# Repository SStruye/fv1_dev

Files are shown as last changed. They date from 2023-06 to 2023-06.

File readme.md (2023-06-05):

# FV1 dev board
the FV1 is a widely used reverb/effect I2C that is programmable.
I build a dev board around it for use as a guitar pedal design platform. <br>

the devboard provides:
-  an onboard usb programmer
-  buffered in and output
-  3 positional dip switch for the FV1,
-  3 variable resistor for the FV1 
-  1 variable resistor for volume 
-  1 variable resistor for mixing the clean and effects signal.

The 3 dip switch can be used to select presets or for use with custom software. The 3 variable resistors are there to adjust paramaters such as time, rise, rate, depth etc. <br>
a 4 layer pcb design was made for better signal integrity.
Some small mistakes are still in the design but it works. (e.g. wrong 3.3V regulator footprint)
Further improvements won't be added for the foreseeable future as intrests shifted.

## PCB design
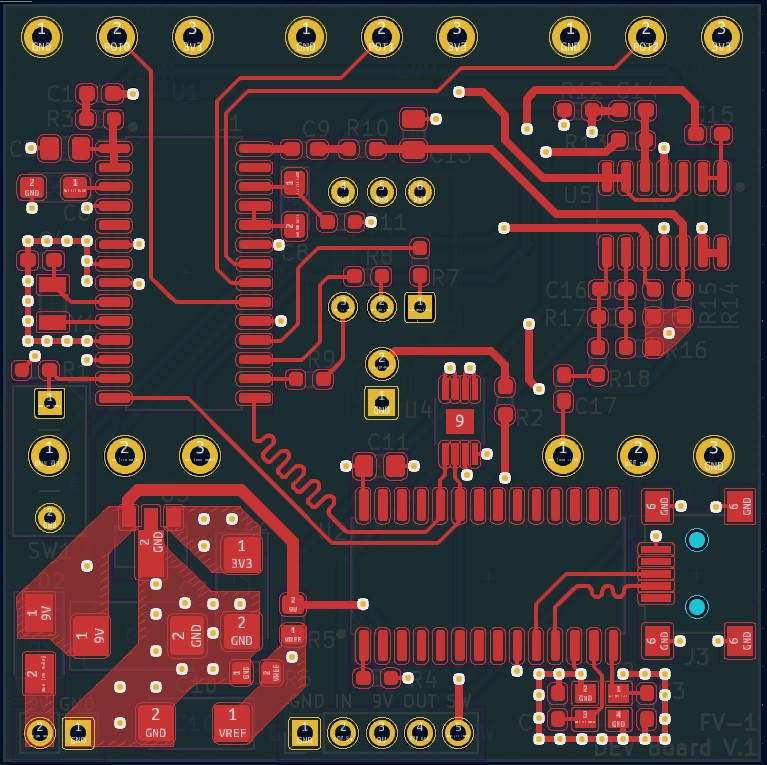
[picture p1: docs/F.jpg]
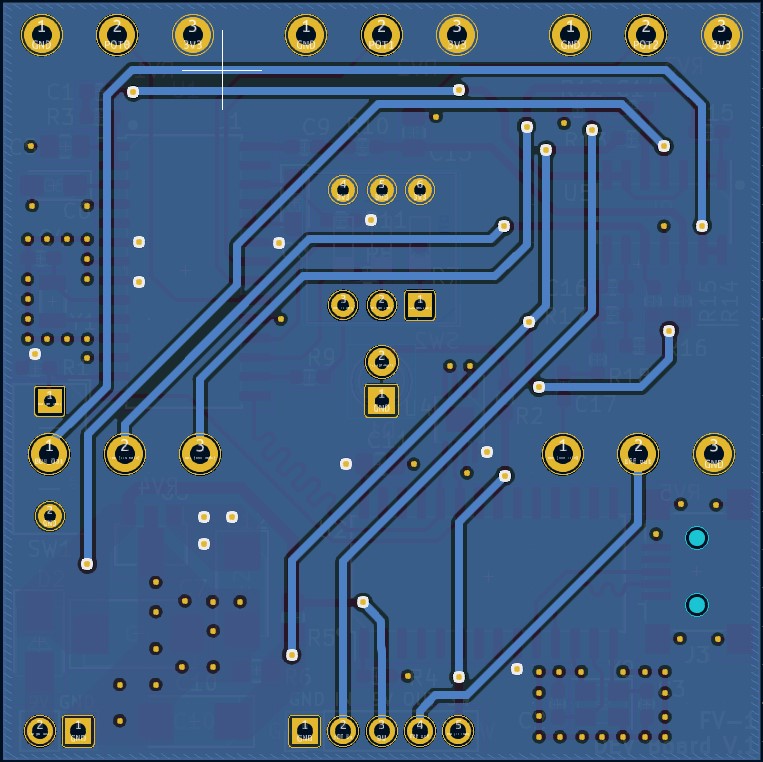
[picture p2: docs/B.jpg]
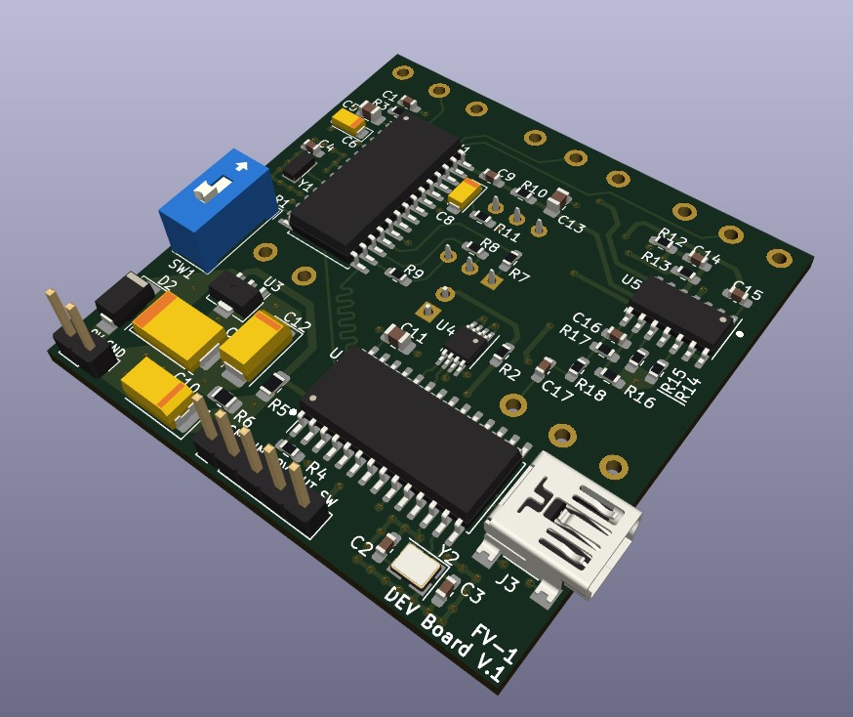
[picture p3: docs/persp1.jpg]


## result
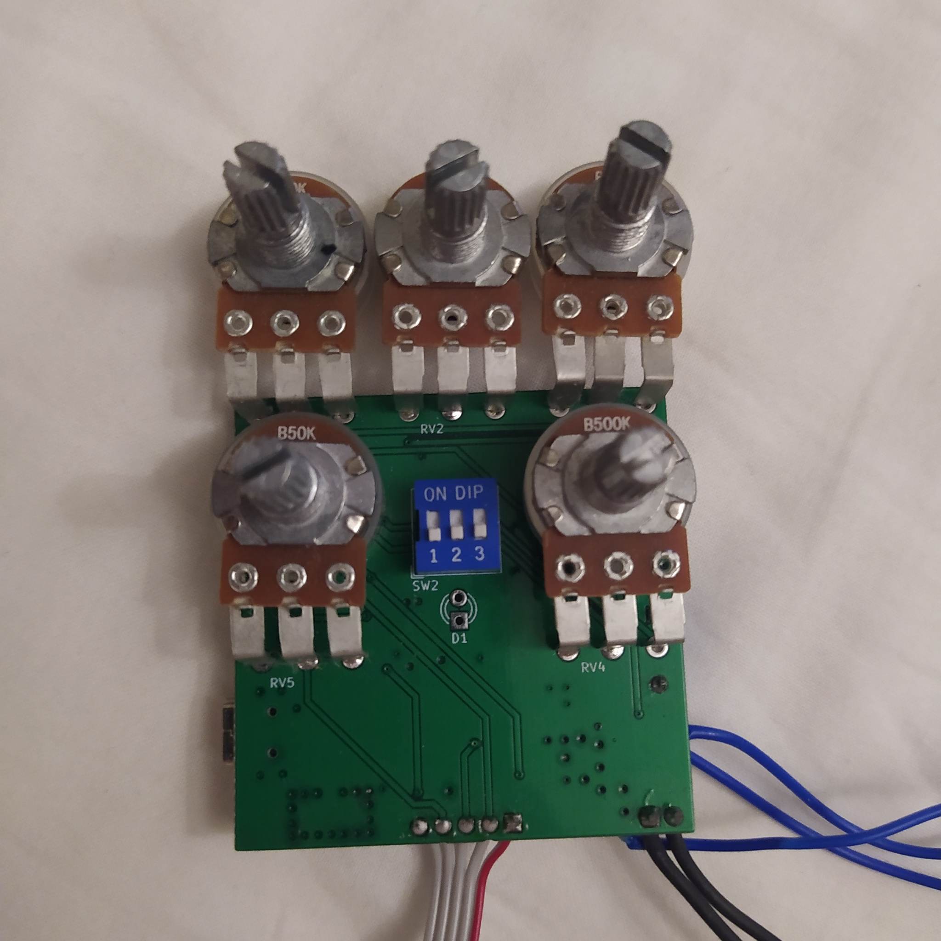
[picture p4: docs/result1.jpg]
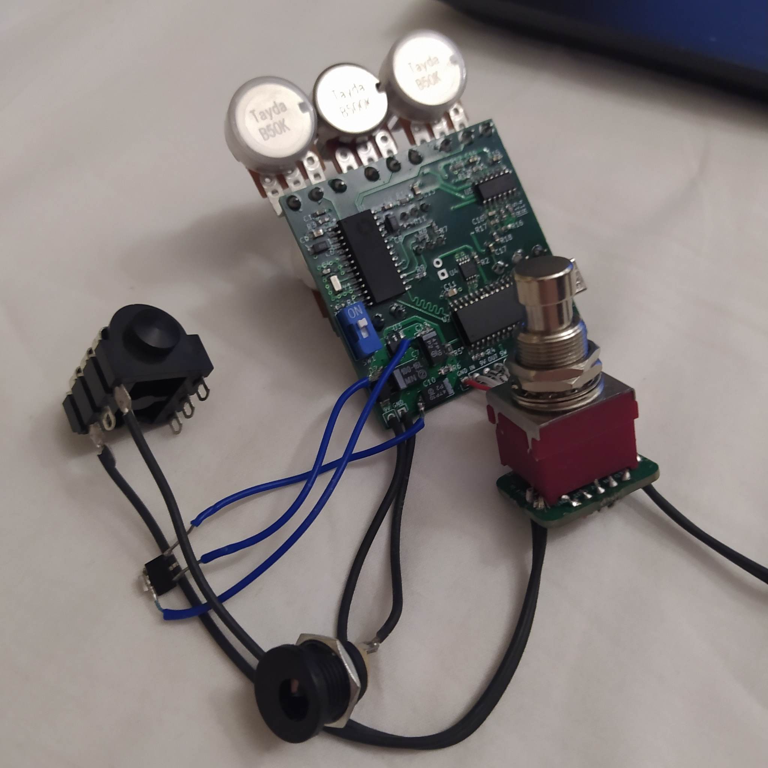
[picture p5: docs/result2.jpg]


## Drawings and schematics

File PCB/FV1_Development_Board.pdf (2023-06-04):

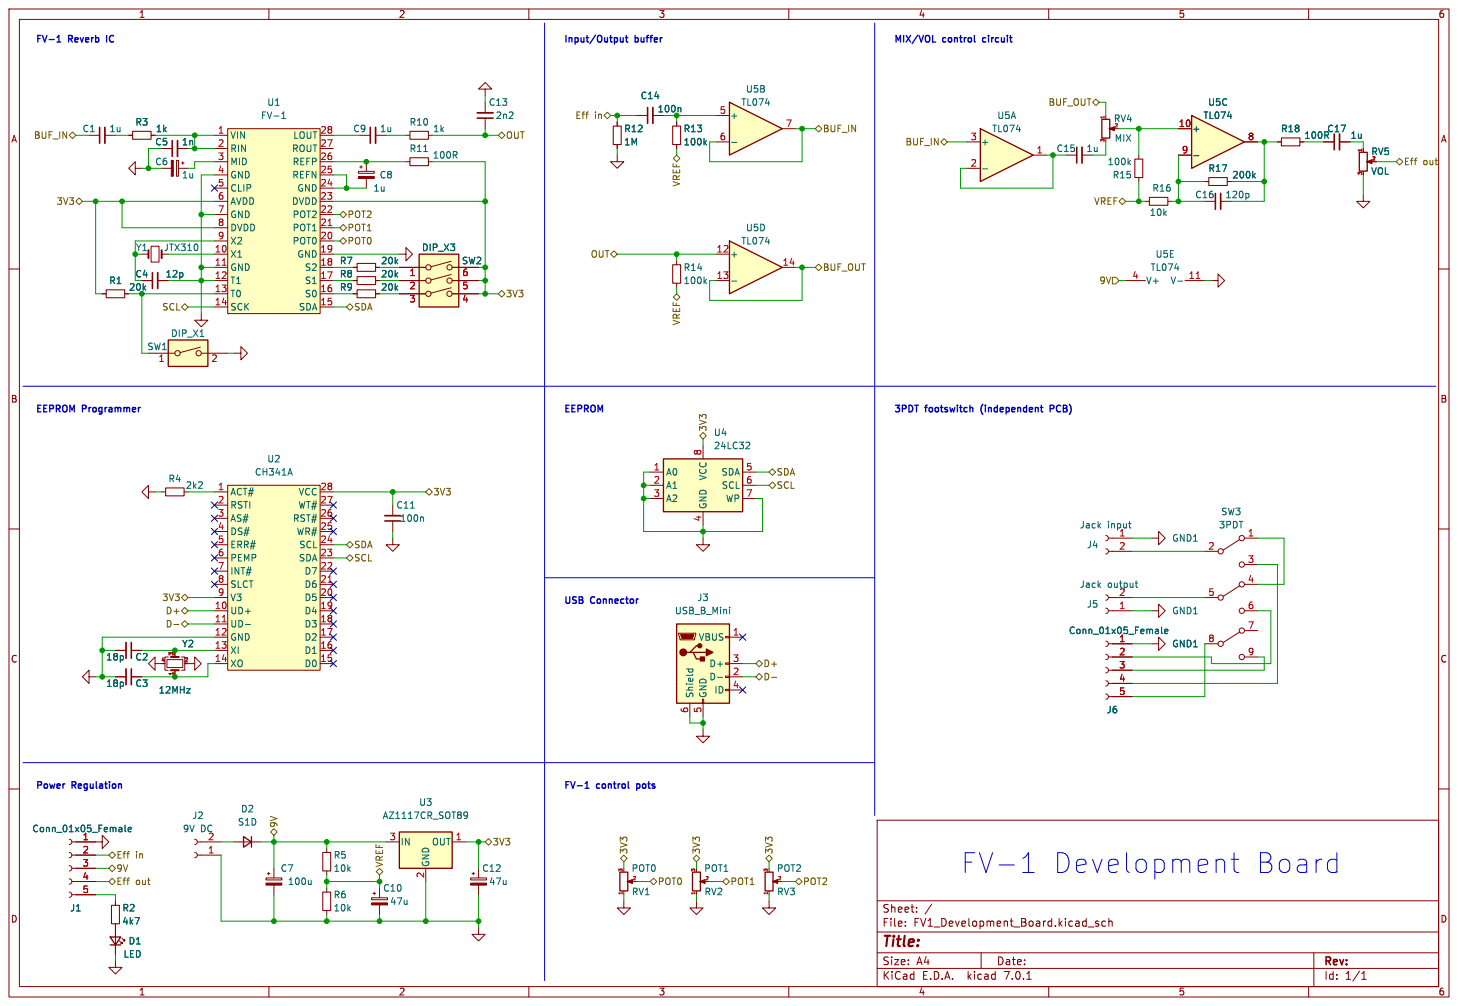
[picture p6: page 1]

4 SDA 5 SCL 6 WP 7 VCC

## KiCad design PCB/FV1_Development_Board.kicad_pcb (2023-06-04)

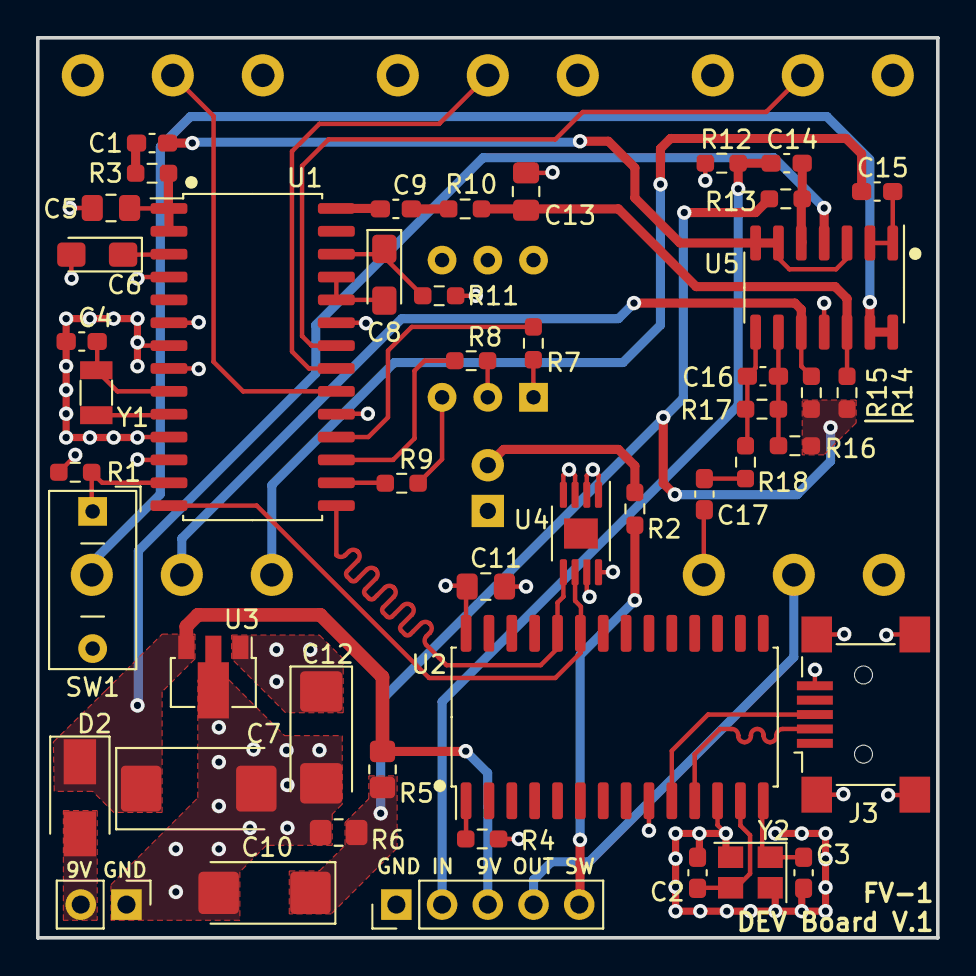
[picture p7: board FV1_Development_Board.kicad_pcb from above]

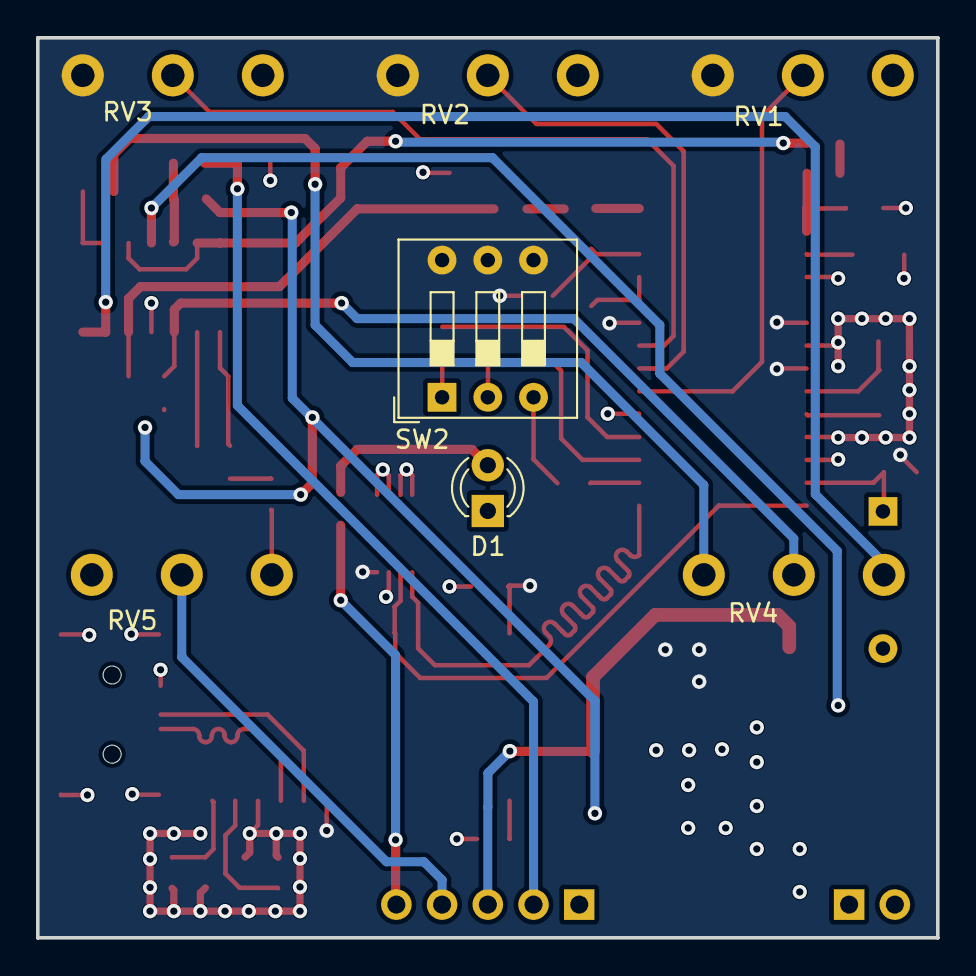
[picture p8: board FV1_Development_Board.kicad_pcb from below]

Board: 4 copper layers, 50.0 x 50.0 mm, 54 parts (7 on the bottom side), 46 nets.

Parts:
9V GND: 9V DC; PinHeader_1x02_P2.54mm_Vertical
C1, C9, C15, C17: 1u; C_0603_1608Metric_Pad1.08x0.95mm_HandSolder
C2, C3: 18p; C_0603_1608Metric_Pad1.08x0.95mm_HandSolder
C4: 12p; C_0603_1608Metric_Pad1.08x0.95mm_HandSolder
C5: 1n; C_0805_2012Metric_Pad1.18x1.45mm_HandSolder
C6, C8: 1u; CP_EIA-3216-10_Kemet-I_Pad1.58x1.35mm_HandSolder
C7: 100u; CP_EIA-7343-20_Kemet-V_Pad2.25x2.55mm_HandSolder
C10, C12: 47u; CP_EIA-6032-28_Kemet-C_Pad2.25x2.35mm_HandSolder
C11: 100n; C_0805_2012Metric_Pad1.18x1.45mm_HandSolder
C13: 2n2; C_0805_2012Metric_Pad1.18x1.45mm_HandSolder
C14: 100n; C_0603_1608Metric_Pad1.08x0.95mm_HandSolder
C16: 120p; C_0603_1608Metric_Pad1.08x0.95mm_HandSolder
D1: LED; LED_D3.0mm
D2: S1D; D_SMA
GND IN  9V OUT SW: Conn_01x05_Female; PinHeader_1x05_P2.54mm_Vertical
J3: USB_B_Mini; USB_Mini-B_Lumberg_2486_01_Horizontal
R1, R7, R8, R9: 20k; R_0603_1608Metric_Pad0.98x0.95mm_HandSolder
R2: 4k7; R_0603_1608Metric_Pad0.98x0.95mm_HandSolder
R3, R10: 1k; R_0603_1608Metric_Pad0.98x0.95mm_HandSolder
R4: 2k2; R_0603_1608Metric_Pad0.98x0.95mm_HandSolder
R5, R6: 10k; R_0805_2012Metric_Pad1.20x1.40mm_HandSolder
R11, R18: 100R; R_0603_1608Metric_Pad0.98x0.95mm_HandSolder
R12: 1M; R_0603_1608Metric_Pad0.98x0.95mm_HandSolder
R13, R14, R15: 100k; R_0603_1608Metric_Pad0.98x0.95mm_HandSolder
R16: 10k; R_0603_1608Metric_Pad0.98x0.95mm_HandSolder
R17: 200k; R_0603_1608Metric_Pad0.98x0.95mm_HandSolder
RV1: POT0; Potentiometer_Omeg_PC16BU_Vertical
RV2: POT1; Potentiometer_Omeg_PC16BU_Vertical
RV3: POT2; Potentiometer_Omeg_PC16BU_Vertical
RV4: MIX; Potentiometer_Omeg_PC16BU_Vertical
RV5: VOL; Potentiometer_Omeg_PC16BU_Vertical
SW1: DIP_X1; SW_DIP_SPSTx01_Slide_9.78x4.72mm_W7.62mm_P2.54mm
SW2: DIP_X3; SW_DIP_SPSTx03_Slide_9.78x9.8mm_W7.62mm_P2.54mm
U1: FV-1; FV1
U2: CH341A
U3: AZ1117CR_SOT89; SOT-89-3
U4: 24LC32; MSOP-8-1EP_3x3mm_P0.65mm_EP1.68x1.88mm
U5: TL074; SOIC-14_3.9x8.7mm_P1.27mm
Y1: JTX310; Crystal_SMD_3215-2Pin_3.2x1.5mm
Y2: 12MHz; Crystal_SMD_Abracon_ABM8G-4Pin_3.2x2.5mm

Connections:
/3V3: C11.2, C12.1, R1.1, R11.2, RV1.3, RV2.3, RV3.3, SW2.4, SW2.5, SW2.6, U1.6 (AVDD), U1.8 (DVDD), U1.23 (DVDD), U2.9 (V3), U2.28 (VCC), U3.1 (OUT), U4.8 (VCC)
/9V: C7.1, D2.1 (K), GND IN 9V OUT SW.3, R5.2, U3.3 (IN), U5.4 (V+)
/BUF_IN: C1.1, U5.3 (+), U5.6 (-), U5.7
/BUF_OUT: RV4.1, U5.13 (-), U5.14
/D+: J3.3 (D+), U2.10 (UD+)
/D-: J3.2 (D-), U2.11 (UD-)
/Eff in: C14.1, GND IN 9V OUT SW.2, R12.2
/Eff out: GND IN 9V OUT SW.4, RV5.2
/OUT: C13.1, R10.2, R14.2, U5.12 (+)
/POT0: RV1.2, U1.20 (POT0)
/POT1: RV2.2, U1.21 (POT1)
/POT2: RV3.2, U1.22 (POT2)
/SCL: U1.14 (SCK), U2.23 (SDA), U4.6 (SCL)
/SDA: U1.15 (SDA), U2.24 (SCL), U4.5 (SDA)
/VREF: C10.1, R5.1, R6.2, R13.1, R14.1, R15.2, R16.1
GND: 9V GND.1, C2.2, C3.2, C4.2, C5.1, C6.2, C7.2, C10.2, C11.1, C12.2, C13.2, D1.1 (K), GND IN 9V OUT SW.1, J3.5 (GND), J3.6 (Shield), R4.1, R6.1, R12.1, RV1.1, RV2.1, RV3.1, RV5.3, SW1.2, U1.4 (GND), U1.7 (GND), U1.11 (GND), U1.12 (T1), U1.19 (GND), U2.12 (GND), U3.2 (GND), U4.1 (A0), U4.2 (A1), U4.3 (A2), U4.4 (GND), U4.7 (WP), U5.11 (V-), Y2.2, Y2.4
unnamed: C1.2, R3.1
unnamed: C2.1, U2.13 (XI), Y2.3
unnamed: C3.1, U2.14 (XO), Y2.1
unnamed: C4.1, U1.9 (X2), Y1.1
unnamed: C5.2, R3.2, U1.1 (VIN), U1.2 (RIN)
unnamed: C6.1, U1.3 (MID)
unnamed: C8.1, R11.1, U1.26 (REFP)
unnamed: C8.2, U1.24 (GND), U1.25 (REFN)
unnamed: C9.1, U1.28 (LOUT)
unnamed: C9.2, R10.1
unnamed: C14.2, R13.2, U5.5 (+)
unnamed: C15.1, U5.1, U5.2 (-)
unnamed: C15.2, RV4.3
unnamed: C16.1, R16.2, R17.1, U5.9 (-)
unnamed: C16.2, R17.2, R18.1, U5.8
unnamed: C17.1, R18.2
unnamed: C17.2, RV5.1
unnamed: D1.2 (A), R2.1
unnamed: 9V GND.2, D2.2 (A)
unnamed: GND IN 9V OUT SW.5, R2.2
unnamed: R1.2, SW1.1, U1.13 (T0)
unnamed: R4.2, U2.1 (ACT#)
unnamed: R7.1, SW2.1
unnamed: R7.2, U1.18 (S2)
unnamed: R8.1, SW2.2
unnamed: R8.2, U1.17 (S1)
unnamed: R9.1, SW2.3
unnamed: R9.2, U1.16 (S0)
unnamed: R15.1, RV4.2, U5.10 (+)
unnamed: U1.10 (X1), Y1.2
